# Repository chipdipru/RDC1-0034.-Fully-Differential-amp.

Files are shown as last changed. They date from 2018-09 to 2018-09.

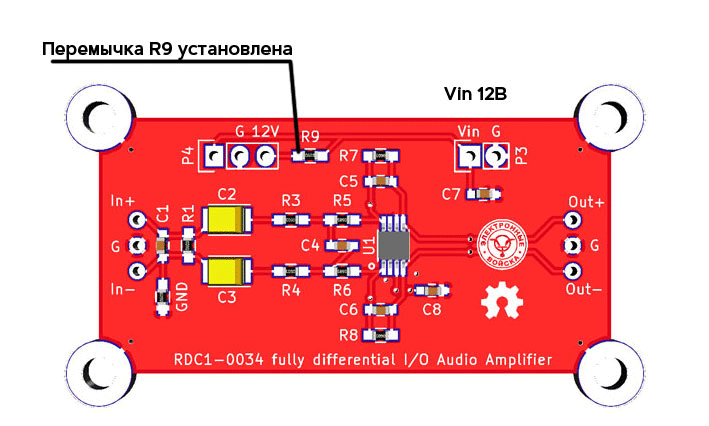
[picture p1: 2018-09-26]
pic0034/RDC1-0034_Vin_800.png

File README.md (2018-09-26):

<p><a href="https://www.chipdip.ru/product/fully-differential-amp.rdc1-0034">RDC1-0034</a> - полностью дифференциальный усилитель. Он обеспечивает высочайшее качество звука с очень низким уровнем шума. Операционный усилитель, рекомендуемый для установки в этот модуль - <a href="https://www.chipdip.ru/product/opa1632dgn" class="link">OPA1632</a>. Он работает в широком диапазоне частот вплоть до 180 МГц и имеет очень высокую скорость нарастания сигнала - 50 В/мкс. Всё это обеспечивает исключительно низкие искажения – 0,000023%.  А очень низкая спектральная плотность шума, всего 1,3 нВ / v Гц, обеспечивает максимальное отношение сигнал-шум и широкий динамический диапазон. Дифференциальные вход и выход уменьшают гармоники четного порядка и минимизирует шумовые помехи. </p><p><h2>Технические характеристики:</h2></p>
Полоса воспроизводимых частот (ограничена активным ФНЧ)  - 1.6Гц…80кГц<br>
Коэффициент нелинейных искажений THD + N @ 1 kHz - 0.000022%<br>
Коэффициент подавления синфазного сигнала – 90дБ<br>
Скорость нарастания выходного сигнала - 50В/мкс<br>
Спектральная плотность шума - 1,3нВ/vГц<br>
Выходной ток – 85мА<br>
Рекомендованное напряжение питания -  12В<br>
Возможное напряжение питания – 5…30В<p><p><h2>Схема</h2></p><p><a href="https://static.chipdip.ru/lib/956/DOC003956118.png" class="galery">Схема</a></p><p>На схеме отображены два корпуса микросхемы OPA1632. Для сборки выбирайте один MSOP-8 или SO-8. </p><p><h2>Монтажная схема</h2></p><p><a href="https://static.chipdip.ru/lib/956/DOC003956117.png" class="galery">Монтажная схема</a></p><p>Обратите внимание. На плате два посадочных. Одно на стороне расположения деталей предназначено для корпуса MSOP-8, а на тыльной стороне для корпуса SO-8.</p><p>Для использования модуля в качестве предварительного усилителя для наших усилителей класса D, рекомендуем запитывать его напряжением 12В. Напряжение питания 12В можно подать непосредственно на вход Vin установив перемычку R9. Если же вы будете использовать модуль совместно с нашими усилителями, то можно будет использовать дополнительный понижающий преобразователь RDC1-0013 12V, который обеспечит питание 12В из 15…48В.</p><p><h2>Схема подключения напряжения питания 12В.</h2></p><p><a href="https://static.chipdip.ru/lib/956/DOC003956120.png" class="galery">12В</a></p><p><h2>Схема подключения напряжения питания 15…48В с помощью <a href="https://www.chipdip.ru/product/rdc1-0013-12v" class="link">RDC1-0013 12V</a></h2></p><p><a href="https://static.chipdip.ru/lib/956/DOC003956115.png" class="galery">48В</a></p><p><h2>Схема подключения напряжения питания 15В с помощью LM7812</h2></p><p><a href="https://static.chipdip.ru/lib/956/DOC003956116.png" class="galery">15В</a></p><p><h2>Не симметричный вход.</h2></p><p>При необходимости подать на вход не симметричный сигнал необходимо установить перемычку GND. </p><p><h2>Эксперимент </h2></p><p>Попробуйте поэкспериментировать: замените операционный усилитель OPA1632 менее дорогими <a href="https://www.chipdip.ru/product/ad8132ar" class="link">AD8132</a> или <a href="https://www.chipdip.ru/product/ad8138arz" class="link">AD8138</a>. Вы приятно удивитесь. Не забудьте, что питание модуля в этом случае не должно превышать Vin = 5В. Используйте <a href="https://www.chipdip.ru/product/rdc1-0013-5v" class="link">RDC1-0013 5V</a> для преобразования напряжения 15-48В или LM7805 для преобразования 15В.</p><p>Это открытый проект! Лицензия, под которой он распространяется – <a href="https://creativecommons.org/licenses/by-sa/3.0/" class="link">Creative Commons - Attribution - Share Alike license</a>.</p>

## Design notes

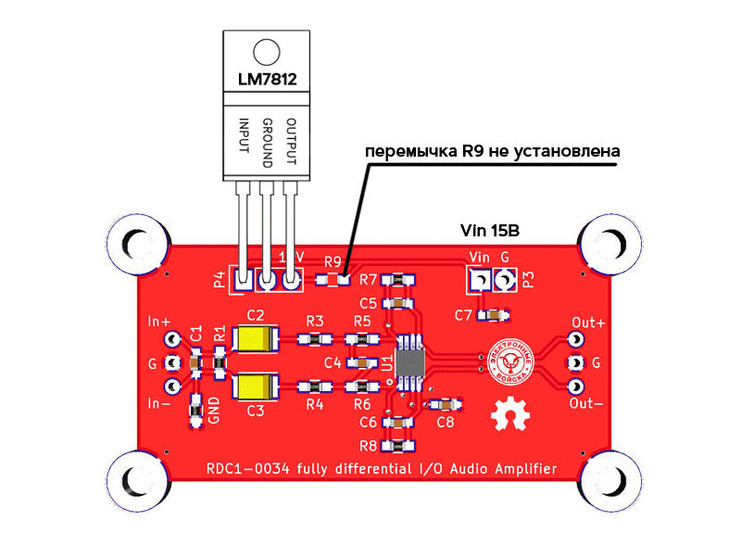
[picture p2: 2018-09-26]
pic0034/RDC1-0034_LM7812_800.png

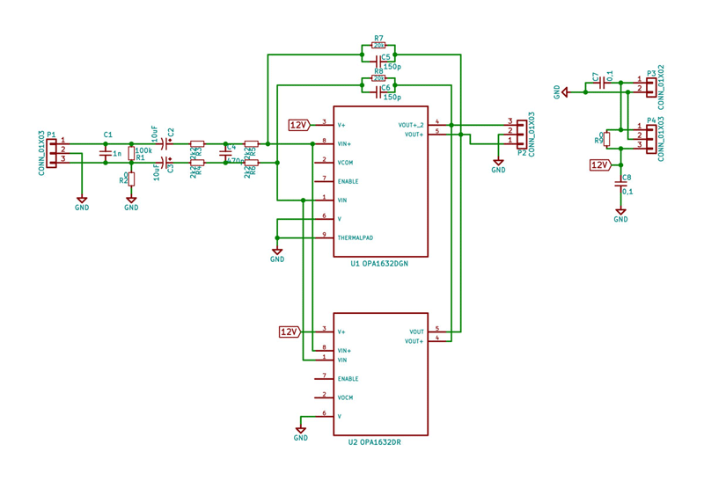
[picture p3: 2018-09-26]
pic0034/RDC1-0034_sch_800.png

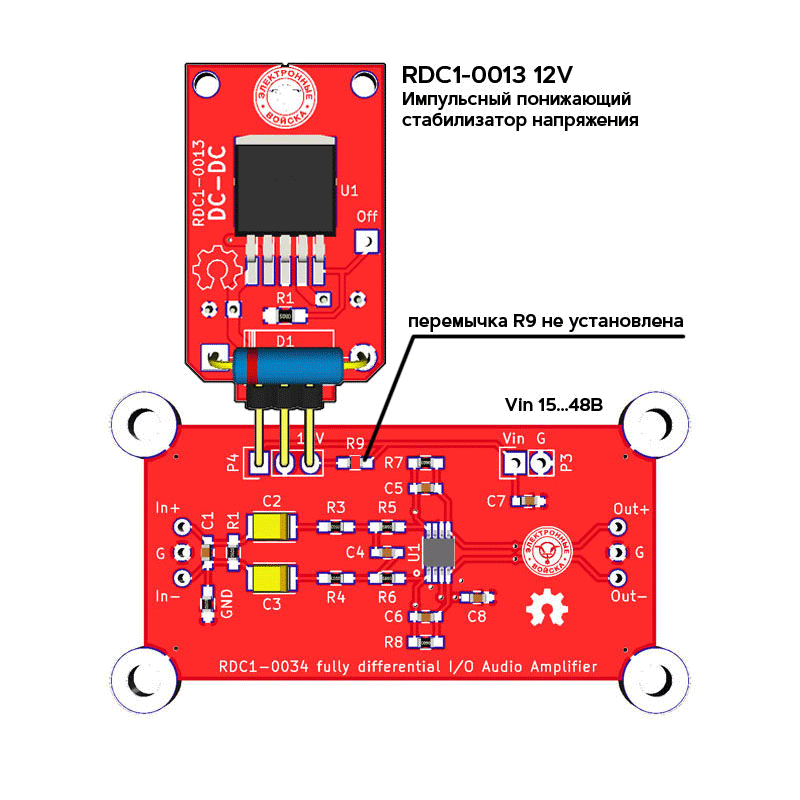
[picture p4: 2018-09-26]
pic0034/RDC1-0034_&_RDC1-0013.png

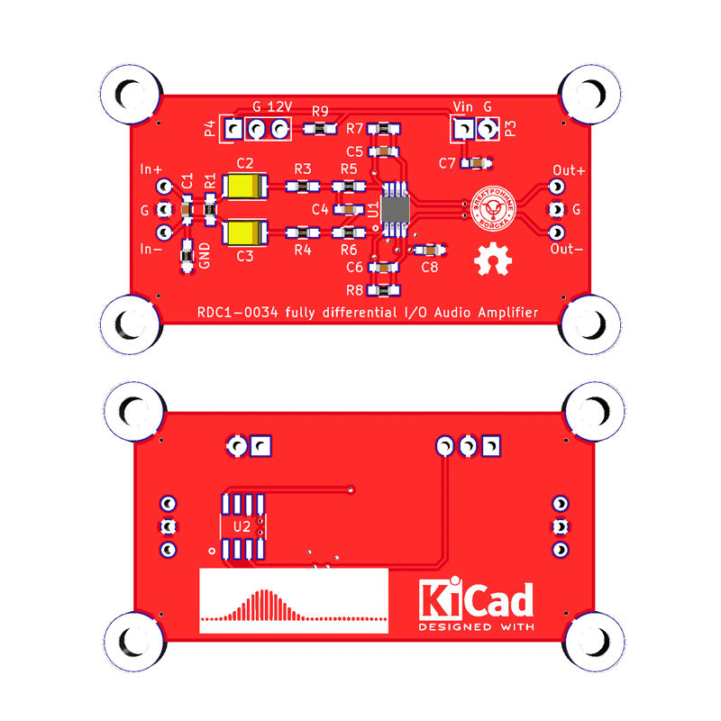
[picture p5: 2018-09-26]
pic0034/RDC1-0034_M_800.png

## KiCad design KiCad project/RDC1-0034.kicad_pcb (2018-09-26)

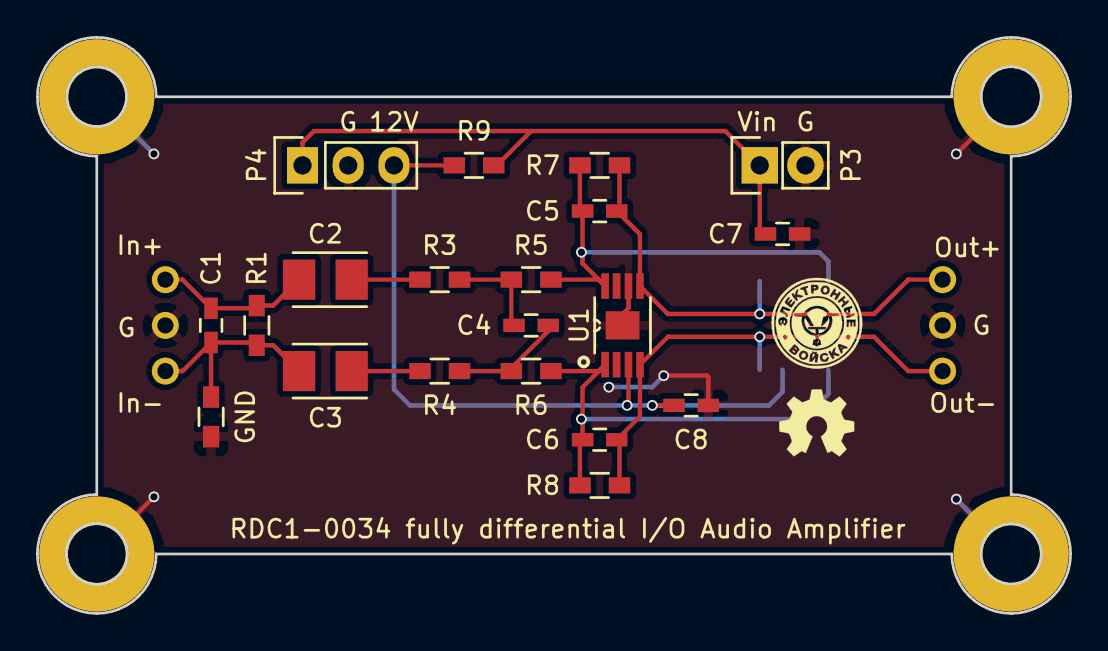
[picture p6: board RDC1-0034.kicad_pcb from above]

Board: 2 copper layers, 57.4 x 32.0 mm, 23 parts (1 on the bottom side), 13 nets.

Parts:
C1: 1n; C_0603_HandSoldering
C2, C3: 10uF; TantalC_SizeB_EIA-3528_Reflow
C4: 470p; C_0603_HandSoldering
C5, C6: 150p; C_0603_HandSoldering
C7, C8: 0,1; C_0603_HandSoldering
GND: 0; R_0603_HandSoldering
P1, P2: CONN_01X03; Pin_Header_ring_1x03_mm
P3: CONN_01X02; Pin_Header_Straight_1x02
P4: CONN_01X03; Pin_Header_Straight_1x03
R1: 100k; R_0603_HandSoldering
R3, R4, R5, R6: 2k2; R_0603_HandSoldering
R7, R8: 20k; R_0603_HandSoldering
R9: 0; R_0603_HandSoldering
U1: OPA1632DGN; SOP65P490X110-9N
U2: OPA1632DR; SOIC127P600X175-8N

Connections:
12V: C8.1, P4.3, R9.1, U1.3, U2.3
GND: C7.1, C8.2, GND.1, P1.2, P2.2, P3.2, P4.2, U1.6, U1.9, U2.6
unnamed: C1.1, C2.2, P1.1, R1.2
unnamed: C1.2, C3.2, GND.2, P1.3, R1.1
unnamed: C2.1, R3.2
unnamed: C3.1, R4.2
unnamed: C4.1, R3.1, R5.2
unnamed: C4.2, R4.1, R6.2
unnamed: C5.1, P2.1, R7.1, U1.5, U2.5
unnamed: C5.2, R5.1, R7.2, U1.8, U2.8
unnamed: C6.1, P2.3, R8.1, U1.4, U2.4
unnamed: C6.2, R6.1, R8.2, U1.1, U2.1
unnamed: C7.2, P3.1, P4.1, R9.2

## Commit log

2018-09-26 KiCad project
    [RDC1-0034.kicad_pcb, RDC1-0034.sch]
2018-09-26 Gerber files
    [RDC1-0034-B.Cu.gbr, RDC1-0034-B.Mask.gbr, RDC1-0034-B.SilkS.gbr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]
